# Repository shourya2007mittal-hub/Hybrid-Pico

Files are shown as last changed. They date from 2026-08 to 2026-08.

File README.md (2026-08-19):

# Hybrid-Pico



So I have designed an RP2040 based Devboard with identical dimensions and pin layout as a A Raspberry Pi Pico . <br>
The board contains the same pin layout and dimensions the RP Pico .<br>
These is a Boot pin for reboot and few onboard LEDS and 3.3V Voltage regulator for power supply to the micro-controllers. <br>
and my design has an upgrade . The Dev-board also includes an inbuilt IMU and Barometer . This broadens the scope of use for this board . As it could be easily connected  to a breadboard and the inbuilt IMU/Barometer sensors helps a lot in during  prototyping a project like a handheld with Gyro , a movement sensor device or  as a  compass or as a flight controller

## Features

- Based on RP-2040 Chip
- Identical Dimension and pin layout as RP-PICO
- 40 physical pins + 3 debugs pin and the board is breadboard compatible 
- Has inbuilt 3.3V  Voltage regulator
- has Inbuilt IMU (MPU-5060) and Barometer (BMP280)

  # Project Bill of Materials (BOM) & Cost Breakdown

This repository contains the hardware components, PCB fabrication, and assembly service details for the project.

---

## 🛠️ Bill of Materials (Components)

| Component / Comment | Quantity | Price (USD) | JLCPCB Part Link |
| :--- | :---: | :---: | :--- |
| **1uF** | 8 | $0.61 | [GRM033R61A105ME44D](https://jlcpcb.com/partdetail/MurataElectronics-GRM033R61A105ME44D/C76935) |
| **10uF** | 16| $0.59 | [CL10A106MQ8NNNC](https://jlcpcb.com/partdetail/2043-CL10A106MQ8NNNC/C1691) |
| **33pF** | 8 | $0.11 | [GRM0335C1H330JA01D](https://jlcpcb.com/partdetail/MurataElectronics-GRM0335C1H330JA01D/C76925) |
| **0.1uF** | 12| $0.15 | [0201X104K100NT](https://jlcpcb.com/partdetail/270391-0201X104K100NT/C284966) |
| **27 ohm** | 4 | $0.15 | [0201X104K100NT](https://jlcpcb.com/partdetail/25843-0402WGF270JTCE/C25100) |
| **100nF** | 8| $0.15 | [GRM033R61A104KE15D](https://jlcpcb.com/partdetail/MurataElectronics-GRM033R61A104KE15D/C76934) |
| **LED** | 6 | $0.68 | [XL0201SURC](https://jlcpcb.com/partdetail/XINGLIGHT-XL0201SURC/C3646923) |
| **USB_C_Receptacle_USB2.0_16P** | 2 | $4.08 | [USB31_TYPE_CFSABC](https://jlcpcb.com/partdetail/GSwitch-GT_USB7010ASV/C2988369) |
| **33R** | 20 | $0.06 | [0201WMJ0330TEE](https://jlcpcb.com/partdetail/416306-0201WMJ0330TEE/C423356) |
| **50K** | 6 | $0.76 | [GL3549](https://jlcpcb.com/partdetail/10622-GL3549/C10083) |
| **1K** | 22 | $0.06 | [0201WMF1001TEE](https://jlcpcb.com/partdetail/259895-0201WMF1001TEE/C270365) |
| **SW_Push** | 4 | $1.86 | [K5_1672SN01](https://jlcpcb.com/partdetail/Korean_HropartsElec-K5_1672SN01/C502360) |
| **MCP1700x-330xxTT** | 2 | $1.03 | [MCP1700_3002ETO](https://jlcpcb.com/partdetail/MicrochipTech-MCP1700T_3302ETT/C39051) |
| **MPU-6050** | 2 | $26.80 | [MPU6050](https://jlcpcb.com/partdetail/TDKInvenSense-MPU6050/C24112) |
| **BMP280** | 2 | $25.58 | [BMP280](https://jlcpcb.com/partdetail/BoschSensortec-BMP280/C83291) |
| **12MHz** | 5 | $1.27 | [NX3225GA_12MHZ](https://jlcpcb.com/partdetail/NDK-NX3225GA_12MHZ_STD_CRG2/C481407) |
| **RP2040** | 0 | $2.47 | [RP2040](https://jlcpcb.com/partdetail/RaspberryPi-RP2040/C2961140) |
| **W25Q16JVUXIQTR** | 2 | $0.987 | [W25Q16JVUXIQTR](https://jlcpcb.com/partdetail/WinbondElec-W25Q16JVUXIQTR/C5333738) |

---

## ⚙️ Fabrication & Assembly Fees

| Service Description | Quantity | Price (USD) |
| :--- | :---: | :---: |
| PCB Fabrication (5 pcs) | 1 | $4.00 |
| PCBA Setup Fee | 1 | $25.56 |
| PCBA Stencil Fee | 1 | $8.21 |
| Feeders Loading Fee | 1 | $19.89 |
| SMT Assembly Fee | 1 | $0.76 |
| Hand-soldering Labor Fee | 1 | $3.58 |
| Manual Assembly Fee | 1 | $0.64 |
| PCB Assembly Fixture | 1 | $16.42 |
| Special Components Fee | 1 | $0.06 |
| Packaging Fee | 1 | $0.49 |
| Shipping Fee | 1 | $11.68 |

---

## 💰 Total Cost

- **Grand Total:** **`$138.29 USD`**

### Schematic 


### PCB Design


Screenshot 2026-08-17 012254 - Copy

### 3D Design




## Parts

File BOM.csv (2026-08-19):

Comment | Quantity | Price | Link
1uF | 8 | $0.61 | https://jlcpcb.com/partdetail/MurataElectronics-GRM033R61A105ME44D/C76935
10uf | 16 | $0.59 | https://jlcpcb.com/partdetail/2043-CL10A106MQ8NNNC/C1691
33pF | 8 | $0.11 | https://jlcpcb.com/partdetail/MurataElectronics-GRM0335C1H330JA01D/C76925
0.1uF | 12 | $0.15 | https://jlcpcb.com/partdetail/270391-0201X104K100NT/C284966
27ohm | 4 | $0.15 | https://jlcpcb.com/partdetail/25843-0402WGF270JTCE/C25100
100nf | 8 | $0.15 | https://jlcpcb.com/partdetail/MurataElectronics-GRM033R61A104KE15D/C76934
LED | 6 | $0.68 | https://jlcpcb.com/partdetail/XINGLIGHT-XL0201SURC/C3646923
USB_C_Receptacle_USB2.0_16P | 2 | $0.28 | https://jlcpcb.com/partdetail/GSwitch-GT_USB7010ASV/C2988369
33R | 8 | $0.06 | https://jlcpcb.com/partdetail/416306-0201WMJ0330TEE/C423356
50K | 6 | $0.76 | https://jlcpcb.com/partdetail/10622-GL3549/C10083
1K | 22 | $0.06 | https://jlcpcb.com/partdetail/259895-0201WMF1001TEE/C270365
SW_Push | 4 | $1.86 | https://jlcpcb.com/partdetail/Korean_HropartsElec-K5_1672SN01/C502360
MCP1700x-330xxTT | 2 | $1.03 | https://jlcpcb.com/partdetail/MicrochipTech-MCP1700T_3302ETT/C39051
MPU-6050 | 2 | $26.80 | https://jlcpcb.com/partdetail/TDKInvenSense-MPU6050/C24112
BMP280 | 2 | $25.58 | https://jlcpcb.com/partdetail/BoschSensortec-BMP280/C83291
12MHz | 2 | $1.27 | https://jlcpcb.com/partdetail/NDK-NX3225GA_12MHZ_STD_CRG2/C481407
RP2040 | 2 | $2.47 | https://jlcpcb.com/partdetail/RaspberryPi-RP2040/C2961140
W25Q16JVUXIQTR | 2 | $0.987 | https://jlcpcb.com/partdetail/WinbondElec-W25Q16JVUXIQTR/C5333738
PCB Fabrication (5 pcs) | 1 | $4.00
PCBA Setup Fee | 1 | $25.56
PCBA Stencil Fee | 1 | $8.21
Feeders Loading Fee | 1 | $19.89
SMT Assembly Fee | 1 | $0.76
Hand-soldering Labor Fee | 1 | $3.58
Manual Assembly Fee | 1 | $0.64
PCB Assembly Fixture | 1 | $16.42
Packaging Fee | 1 | $0.49
Special Components Fee | 1 | $0.06
Shipping Fee | 1 | $11.68
Total |  | $138.29

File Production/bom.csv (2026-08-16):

Designator | Footprint | Quantity | Value | LCSC Part #
C1, C91 | 0201 | 2 | 1uF
C12 | 0201 | 1 | 10 uf
C13, C14 | 0201 | 2 | 10uF
C15, C16 | 0201 | 2 | 33pF
C17, C18, C19, C2, C3, C4 | 0201 | 6 | 0.1uF
C20, C21, C232 | 0201 | 3 | 100 nf
C226, C88 | 0402 | 2 | 100 nf
C45 | 0201 | 1 | 0.1 uf
C71 | 0402 | 1 | 1uF
D1, D4, D5 | 0201 | 3 | LED
J1 | USB_C_Receptacle_G-Switch_GT-USB-7010ASV | 1 | USB_C_Receptacle_USB2.0_16P
J2, J3 | PinHeader_1x20_P2.54mm_Vertical | 2 | Conn_01x20
J4 | PinHeader_1x03_P2.54mm_Vertical | 1 | Conn_01x03
R10, R104, R145, R15 | 0402 | 4 | 4.7K
R11, R12, R13, R5, R6 | 0201 | 5 | 1K
R14 | 0603 | 1 | 10K
R3, R4 | 0201 | 2 | 50K
R7 | 0201 | 1 | 10K
R81, R91 | 0402 | 2 | 27
SW1, SW3 | SW_Push_SPST_NO_Alps_SKRK | 2 | SW_Push
U1 | QFN-56-1EP_7x7mm_P0.4mm_EP3.2x3.2mm | 1 | RP2040
U2 | SOT-23 | 1 | MCP1700x-330xxTT
U4 | Winbond_USON-8-1EP_3x2mm_P0.5mm_EP0.2x1.6mm | 1 | W25Q16JVUXIQ TR
U5 | InvenSense_QFN-24_4x4mm_P0.5mm | 1 | MPU-6050
U6 | Bosch_LGA-8_2x2.5mm_P0.65mm_ClockwisePinNumbering | 1 | BMP280
Y1 | Crystal_SMD_3225-4Pin_3.2x2.5mm | 1 | 12 MHz

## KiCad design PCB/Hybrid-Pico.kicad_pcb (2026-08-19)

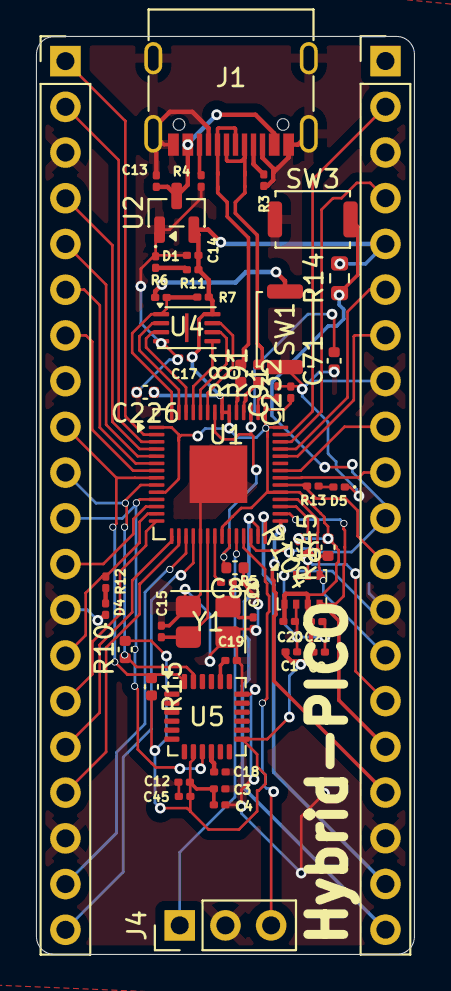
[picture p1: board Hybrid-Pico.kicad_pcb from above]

Board: 2 copper layers, 21.0 x 51.0 mm, 50 parts (0 on the bottom side), 58 nets.

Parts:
C1: 1uF; C_0201_0603Metric
C2, C3, C4, C17: 0.1uF; C_0201_0603Metric
C12: 10 uf; C_0201_0603Metric
C13, C14: 10uF; C_0201_0603Metric
C15, C16: 33pF; C_0201_0603Metric
C18, C19: 0.1uf; C_0201_0603Metric
C20, C21, C232: 100 nf; C_0201_0603Metric
C45: 0.1 uf; C_0201_0603Metric
C71: 1uF; C_0402_1005Metric
C88, C226: 100 nf; C_0402_1005Metric
C91: 1uf; C_0201_0603Metric
D1, D4, D5: LED; LED_0201_0603Metric
J1: USB_C_Receptacle_USB2.0_16P; USB_C_Receptacle_G-Switch_GT-USB-7010ASV
J2, J3: Conn_01x20; PinHeader_1x20_P2.54mm_Vertical
J4: Conn_01x03; PinHeader_1x03_P2.54mm_Vertical
R3, R4: 50K; C_0201_0603Metric
R5, R6, R11, R12, R13: 1K; C_0201_0603Metric
R7: 10K; C_0201_0603Metric
R10, R15, R104, R145: 5.1K; C_0402_1005Metric
R14: 10K; R_0603_1608Metric
R81, R91: 27; C_0402_1005Metric
SW1, SW3: SW_Push; SW_Push_SPST_NO_Alps_SKRK
U1: RP2040; QFN-56-1EP_7x7mm_P0.4mm_EP3.2x3.2mm
U2: MCP1700x-330xxTT; SOT-23
U4: W25Q16JVUXIQ TR; Winbond_USON-8-1EP_3x2mm_P0.5mm_EP0.2x1.6mm
U5: MPU-6050; InvenSense_QFN-24_4x4mm_P0.5mm
U6: BMP280; Bosch_LGA-8_2x2.5mm_P0.65mm_ClockwisePinNumbering
Y1: 12 MHz; Crystal_SMD_3225-4Pin_3.2x2.5mm

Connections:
3.3V: C1.1, C2.1, C3.1, C4.1, C12.1, C14.1, C17.1, C20.1, C21.1, C45.1, C91.1, C226.1, C232.1, J3.5, R7.2, R11.1, R14.2, R104.2, R145.2, U1.1 (IOVDD), U1.10 (IOVDD), U1.22 (IOVDD), U1.33 (IOVDD), U1.42 (IOVDD), U1.43 (ADC_AVDD), U1.44 (VREG_IN), U1.48 (USB_VDD), U1.49 (IOVDD), U2.2 (VO), U4.8 (VCC), U5.8 (VLOGIC), U5.13 (VDD), U6.6 (VDDIO), U6.8 (VDD)
5V: C13.1, J1.A4 (VBUS), J1.A9 (VBUS), J1.B4 (VBUS), J1.B9 (VBUS), U2.3 (VI)
+3.3V: R10.2, R15.2
AD1: J2.11, U1.11 (GPIO8), U5.9 (AD0)
AD2: J3.16, U1.30 (GPIO19), U6.5 (SDO)
GND: C1.2, C2.2, C3.2, C4.2, C12.2, C13.2, C14.2, C15.1, C16.1, C17.2, C18.2, C19.2, C20.2, C21.2, C45.2, C71.1, C88.1, C91.2, C226.2, C232.2, D1.1 (K), D4.1 (K), D5.1 (K), J1.A1 (GND), J1.A8 (SBU1), J1.A12 (GND), J1.B1 (GND), J1.B8 (SBU2), J1.B12 (GND), J1.S1 (SHIELD), J2.3, J2.8, J2.13, J2.18, J3.3, J3.8, J3.13, J3.18, J4.2, R3.2, R4.2, SW1.1, SW3.1, U1.19 (TESTEN), U1.57 (GND), U2.1 (GND), U4.4 (GND), U5.18 (GND), U6.1 (GND), U6.7 (GND), Y1.2, Y1.4
GPIO0: J2.1, U1.2 (GPIO0)
GPIO1: J2.2, U1.3 (GPIO1)
GPIO2: J2.4, U1.4 (GPIO2)
GPIO3: J2.5, U1.5 (GPIO3)
GPIO4: J2.6, U1.6 (GPIO4)
GPIO5: J2.7, U1.7 (GPIO5)
GPIO6: J2.9, R15.1, U1.8 (GPIO6), U5.24 (SDA)
GPIO7: J2.10, R10.1, U1.9 (GPIO7), U5.23 (SCL)
GPIO9: J2.12, U1.12 (GPIO9)
GPIO10: J2.14, R12.1, U1.13 (GPIO10)
GPIO11: J2.15, U1.14 (GPIO11)
GPIO12: J2.16, U1.15 (GPIO12)
GPIO13: J2.17, U1.16 (GPIO13)
GPIO14: J2.19, U1.17 (GPIO14)
GPIO15: J2.20, U1.18 (GPIO15)
GPIO16: J3.20, U1.27 (GPIO16)
GPIO17: J3.19, U1.28 (GPIO17)
GPIO18: J3.17, U1.29 (GPIO18)
GPIO20: J3.15, R104.1, U1.31 (GPIO20), U6.3 (SDI)
GPIO21: J3.14, R145.1, U1.32 (GPIO21), U6.4 (SCK)
GPIO22: J3.12, R13.1, U1.34 (GPIO22)
GPIO23: J3.10, U1.35 (GPIO23)
GPIO24: J3.9, U1.36 (GPIO24)
GPIO26_ADC0: J3.7, U1.38 (GPIO26_ADC0)
GPIO27_ADC1: J3.6, U1.39 (GPIO27_ADC1)
GPIO28_ADC2: J3.4, U1.40 (GPIO28_ADC2)
GPIO29_ADC3: J3.2, U1.41 (GPIO29_ADC3)
unnamed: C16.2, R5.1, Y1.1
unnamed: D1.2 (A), R11.2
unnamed: D4.2 (A), R12.2
unnamed: D5.2 (A), R13.2
unnamed: J1.A5 (CC1), R3.1
unnamed: J1.B5 (CC2), R4.1
unnamed: J1.A6 (D+), J1.B6 (D+)
unnamed: J1.A7 (D-), J1.B7 (D-)
unnamed: R6.2, SW1.2
unnamed: C88.2, U1.23 (DVDD), U1.45 (VREG_VOUT), U1.50 (DVDD)
unnamed: C19.1, U5.20 (CPOUT)
unnamed: C18.1, U5.10 (REGOUT)
QSPI_SCLK: U1.52 (QSPI_SCLK), U4.6 (CLK)
QSPI_SD0: U1.53 (QSPI_SD0), U4.5 (DI/IO_{0})
QSPI_SD1: U1.55 (QSPI_SD1), U4.2 (DO/IO_{1})
QSPI_SD2: U1.54 (QSPI_SD2), U4.3 (~WP/IO_{2})
QSPI_SD3: U1.51 (QSPI_SD3), U4.7 (~HOLD/~RESET/IO_{3})
QSPI_SS: R6.1, R7.1, U1.56 (QSPI_SS), U4.1 (~CS)
RUN: J3.11, SW3.2, U1.26 (RUN)
SWCLK: J4.1, U1.24 (SWCLK)
SWD: J4.3, U1.25 (SWD)
XIN: C15.2, U1.20 (XIN), Y1.3
XOUT: R5.2, U1.21 (XOUT)
_D+: R81.1, U1.47 (USB_DP)
_D-: R91.1, U1.46 (USB_DM)
